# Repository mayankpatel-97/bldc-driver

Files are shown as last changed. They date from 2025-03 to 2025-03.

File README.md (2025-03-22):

# BLDC Driver

## Overview
This project is an open-source BLDC motor driver designed for drone applications. It implements a sensorless control method using **Back EMF** for efficient and precise motor control.

## Motor Control Methods
There are multiple ways to drive a BLDC motor. The three most common methods are:

1. **Hall Sensor-Based Control**  
   - Uses **hall effect sensors** in the motor to detect rotor position.
   - Suitable for applications requiring high precision.

2. **Back EMF-Based Control (Sensorless)**  
   - Most **common in drone ESCs** (Electronic Speed Controllers).
   - Detects rotor position by measuring **Back EMF voltage** on the floating phase.
   - Eliminates the need for sensors, reducing cost and complexity.

3. **Power Control Mode**  
   - Uses **shunt resistors** to monitor **current in each phase**.
   - Enables precise **torque and power control**.
   - Required for advanced techniques like **Field-Oriented Control (FOC)**.

## Current Implementation
- **Control Method**: Back EMF sensing (sensorless)  
- **Target Application**: Drone ESC

## Future Enhancements
- **CAN Bus Interface** for communication
- **UART Interface** for debugging and configuration
- In the next varient, one board would have the driver for all the 4 motors required for quad copter.

## PCB information 
- Generated gerber files are in gerber folder of the project directory
- PCB file size: 54x29 mm.

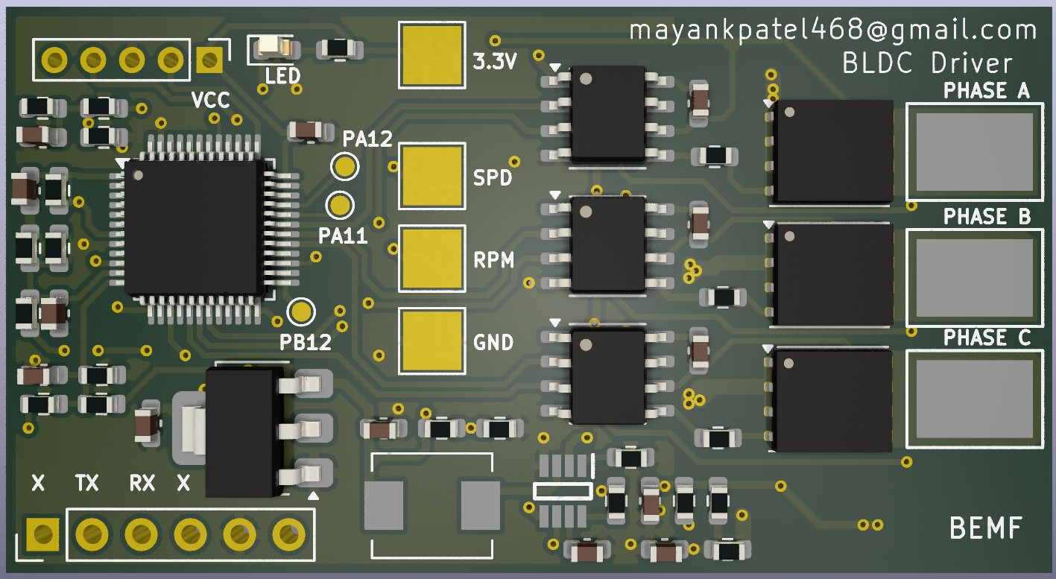
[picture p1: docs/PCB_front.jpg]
PCB


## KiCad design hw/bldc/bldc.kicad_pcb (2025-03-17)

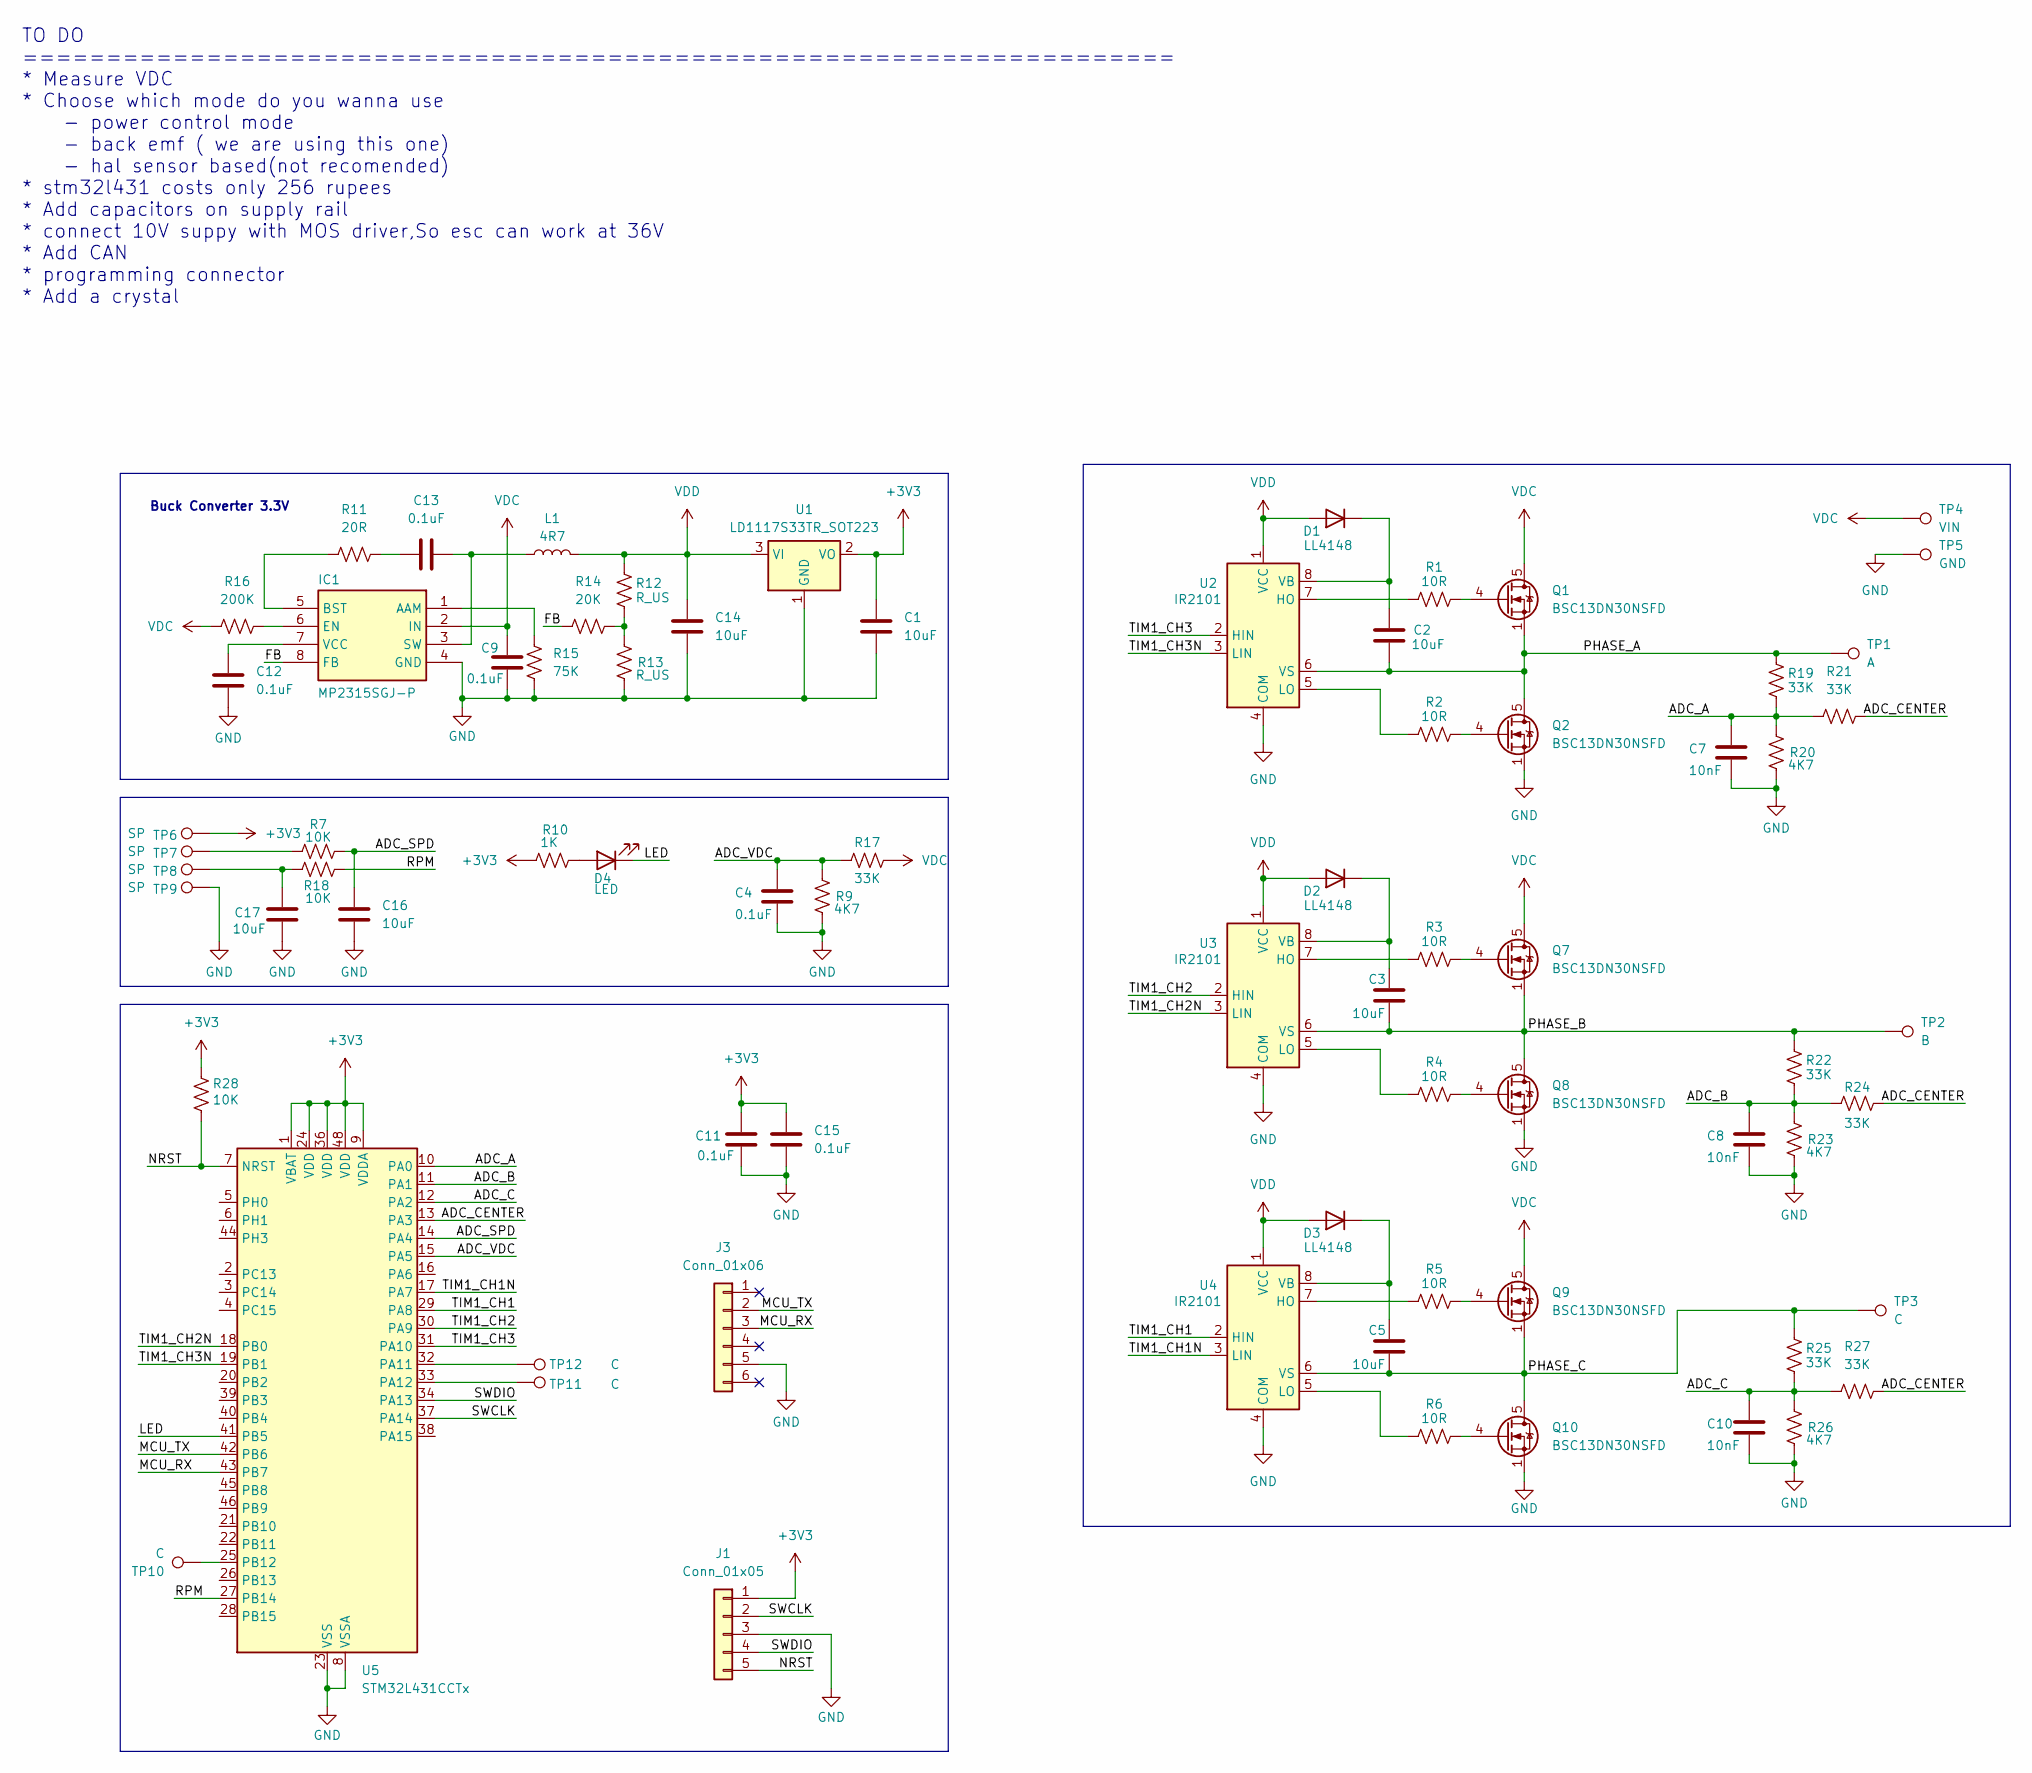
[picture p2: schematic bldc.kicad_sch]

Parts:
C1, C2, C3, C5, C14, C16, C17: 10uF; C_0603_1608Metric
C4, C9, C11, C12, C13, C15: 0.1uF; C_0603_1608Metric
C7, C8, C10: 10nF; C_0603_1608Metric
D1, D2, D3: LL4148; D_MiniMELF
D4: LED; LED_0603_1608Metric
IC1: MP2315SGJ-P; MP2315SGJ; Manufacturer_Part_Number MP2315SGJ-P; Mouser Part Number 946-MP2315SGJ-P
J1: Conn_01x05; PinHeader_1x05_P2.00mm_Vertical
J3: Conn_01x06; PinHeader_1x06_P2.54mm_Vertical
L1: 4R7; L_Neosid_SM-PIC0512H
Q1, Q2, Q7, Q8, Q9, Q10: BSC13DN30NSFD; TDSON-8-1
R1, R2, R3, R4, R5, R6: 10R; R_0603_1608Metric
R7, R18, R28: 10K; R_0603_1608Metric
R9, R20, R23, R26: 4K7; R_0603_1608Metric
R10: 1K; R_0603_1608Metric
R11: 20R; R_0603_1608Metric
R12, R13: R_US; R_0603_1608Metric
R14: 20K; R_0603_1608Metric
R15: 75K; R_0603_1608Metric
R16: 200K; R_0603_1608Metric
R17, R19, R21, R22, R24, R25, R27: 33K; R_0603_1608Metric
TP1: A; SOLDERPAD6x4
TP2: B; SOLDERPAD6x4
TP3: C; SOLDERPAD6x4
TP4: VIN; SOLDERPAD6x4
TP5: GND; SOLDERPAD6x4
TP6, TP7, TP8, TP9: SP; TestPoint_Pad_3.0x3.0mm
TP10, TP11, TP12: C; TestPoint_Pad_D1.0mm
U1: LD1117S33TR_SOT223; SOT-223-3_TabPin2
U2, U3, U4: IR2101; SOIC-8_3.9x4.9mm_P1.27mm
U5: STM32L431CCTx; LQFP-48_7x7mm_P0.5mm

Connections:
+3V3: C1.2, C11.2, C15.2, J1.1, R10.1, R28.2, TP6.1, U1.2 (VO), U5.1 (VBAT), U5.9 (VDDA), U5.24 (VDD), U5.36 (VDD), U5.48 (VDD)
/ADC_A: C7.1, R19.2, R20.1, R21.1, U5.10 (PA0)
/ADC_B: C8.1, R22.2, R23.1, R24.1, U5.11 (PA1)
/ADC_C: C10.1, R25.2, R26.1, R27.1, U5.12 (PA2)
/ADC_CENTER: R21.2, R24.2, R27.2, U5.13 (PA3)
/ADC_SPD: C16.2, R18.1, U5.14 (PA4)
/ADC_VDC: C4.1, R9.1, R17.1, U5.15 (PA5)
/FB: IC1.8 (FB), R14.1
/LED: D4.1 (K), U5.41 (PB5)
/MCU_RX: J3.3, U5.43 (PB7)
/MCU_TX: J3.2, U5.42 (PB6)
/NRST: J1.5, R28.1, U5.7 (NRST)
/PHASE_A: C2.2, Q1.1 (S), Q1.2 (S), Q1.3 (S), Q2.5 (D), R19.1, TP1.1, U2.6 (VS)
/PHASE_B: C3.2, Q7.1 (S), Q7.2 (S), Q7.3 (S), Q8.5 (D), R22.1, TP2.1, U3.6 (VS)
/PHASE_C: C5.2, Q9.1 (S), Q9.2 (S), Q9.3 (S), Q10.5 (D), R25.1, TP3.1, U4.6 (VS)
/RPM: R7.1, U5.27 (PB14)
/SWCLK: J1.2, U5.37 (PA14)
/SWDIO: J1.4, U5.34 (PA13)
/TIM1_CH1: U4.2 (HIN), U5.29 (PA8)
/TIM1_CH1N: U4.3 (LIN), U5.17 (PA7)
/TIM1_CH2: U3.2 (HIN), U5.30 (PA9)
/TIM1_CH2N: U3.3 (LIN), U5.18 (PB0)
/TIM1_CH3: U2.2 (HIN), U5.31 (PA10)
/TIM1_CH3N: U2.3 (LIN), U5.19 (PB1)
GND: C1.1, C4.2, C7.2, C8.2, C9.2, C10.2, C11.1, C12.2, C14.1, C15.1, C16.1, C17.1, IC1.4 (GND), J1.3, J3.5, Q2.1 (S), Q2.2 (S), Q2.3 (S), Q8.1 (S), Q8.2 (S), Q8.3 (S), Q10.1 (S), Q10.2 (S), Q10.3 (S), R9.2, R13.2, R15.2, R20.2, R23.2, R26.2, TP5.1, TP9.1, U1.1 (GND), U2.4 (COM), U3.4 (COM), U4.4 (COM), U5.8 (VSSA), U5.23 (VSS), U5.35 (VSS), U5.47 (VSS)
unnamed: C13.1, R11.2
unnamed: C17.2, R7.2, TP8.1
unnamed: C2.1, D1.1 (K), U2.8 (VB)
unnamed: C3.1, D2.1 (K), U3.8 (VB)
unnamed: C5.1, D3.1 (K), U4.8 (VB)
unnamed: D4.2 (A), R10.2
unnamed: IC1.1 (AAM), R15.1
unnamed: IC1.5 (BST), R11.1
unnamed: IC1.6 (EN), R16.2
unnamed: C13.2, IC1.3 (SW), L1.1
unnamed: C12.1, IC1.7 (VCC)
unnamed: Q1.4 (G), R1.2
unnamed: Q2.4 (G), R2.2
unnamed: Q7.4 (G), R3.2
unnamed: Q8.4 (G), R4.2
unnamed: Q9.4 (G), R5.2
unnamed: Q10.4 (G), R6.2
unnamed: R12.2, R13.1, R14.2
unnamed: R18.2, TP7.1
unnamed: R1.1, U2.7 (HO)
unnamed: R2.1, U2.5 (LO)
unnamed: R3.1, U3.7 (HO)
unnamed: R4.1, U3.5 (LO)
unnamed: R5.1, U4.7 (HO)
unnamed: R6.1, U4.5 (LO)
unnamed: TP12.1, U5.32 (PA11)
unnamed: TP11.1, U5.33 (PA12)
unnamed: TP10.1, U5.25 (PB12)
VDC: C9.1, IC1.2 (IN), Q1.5 (D), Q7.5 (D), Q9.5 (D), R16.1, R17.2, TP4.1
VDD: C14.2, D1.2 (A), D2.2 (A), D3.2 (A), L1.2, R12.1, U1.3 (VI), U2.1 (VCC), U3.1 (VCC), U4.1 (VCC)

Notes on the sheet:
TO DO ===================================================================== * Measure VDC * Choose which mode do you wanna use - power control mode - back emf ( we are using this one) - hal sensor based(not recomended) * stm32l431 costs only 256 rupees * Add capacitors on supply rail * connect 10V 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
Buck Converter 3.3V

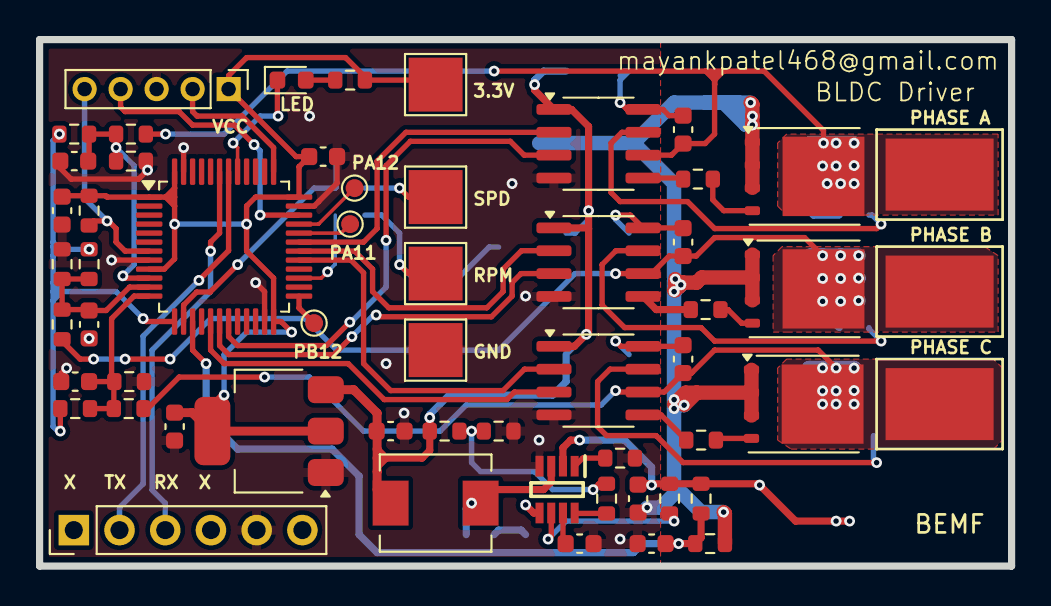
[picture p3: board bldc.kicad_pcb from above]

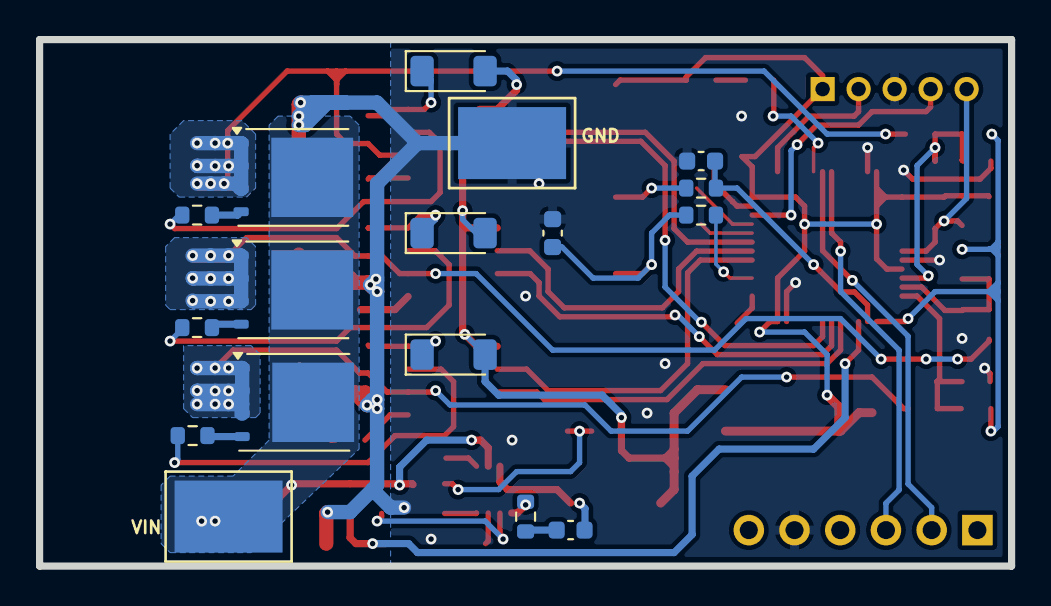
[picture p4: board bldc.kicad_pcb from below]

Board: 2 copper layers, 54.0 x 29.2 mm, 74 parts (17 on the bottom side), 55 nets.

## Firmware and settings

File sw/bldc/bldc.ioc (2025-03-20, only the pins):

Mcu.UserName=STM32L431CCTx
PA0.Signal=ADCx_IN5
PA1.Signal=ADCx_IN6
PA10.Signal=S_TIM1_CH3
PA2.Signal=ADCx_IN7
PA3.Signal=ADCx_IN8
PA4.Signal=ADCx_IN9
PA7.GPIO_Label=PHASE_A_L
PA7.Signal=GPIO_Output
PA8.Signal=S_TIM1_CH1
PA9.Signal=S_TIM1_CH2
PB0.GPIO_Label=PHASE_B_L
PB0.Signal=GPIO_Output
PB1.GPIO_Label=PHASE_C_L
PB1.Signal=GPIO_Output
PB14.Signal=S_TIM15_CH1
PB5.GPIO_Label=LED
PB5.Signal=GPIO_Output
PB6.Signal=USART1_TX
PB7.Signal=USART1_RX

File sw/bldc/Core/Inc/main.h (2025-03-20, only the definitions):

#define PHASE_A_L_Pin GPIO_PIN_7
#define PHASE_A_L_GPIO_Port GPIOA
#define PHASE_B_L_Pin GPIO_PIN_0
#define PHASE_B_L_GPIO_Port GPIOB
#define PHASE_C_L_Pin GPIO_PIN_1
#define PHASE_C_L_GPIO_Port GPIOB
#define LED_Pin GPIO_PIN_5
#define LED_GPIO_Port GPIOB

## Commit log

2025-03-14 added kicad project
    [bldc.kicad_pcb, bldc.kicad_sch]
2025-03-14 schematic update
    [bldc.kicad_sch]
2025-03-14 sch update using BEMF
    [bldc.kicad_sch]
2025-03-15 pcb update
    [bldc.kicad_pcb, bldc.kicad_sch]
2025-03-16 component placement
    [bldc.kicad_pcb, bldc.kicad_sch]
2025-03-16 pcb routing update
    [bldc.kicad_pcb, bldc.kicad_sch]
2025-03-16 Gerber Generated
    [bldc-B_Cu.gbr, bldc-B_Mask.gbr, bldc-B_Paste.gbr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]
2025-03-17 made some corrections
    [bldc-B_Cu.gbr, bldc-B_Mask.gbr, bldc-B_Paste.gbr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]
2025-03-22 added pcb pic in README.md

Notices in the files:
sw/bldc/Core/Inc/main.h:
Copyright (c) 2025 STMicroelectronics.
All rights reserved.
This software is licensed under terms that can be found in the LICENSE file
